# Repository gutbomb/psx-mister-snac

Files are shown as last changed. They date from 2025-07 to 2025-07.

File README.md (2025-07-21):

# psx-mister-snac

This is based on schematics published here: https://github.com/blue212/SNAC-PSX

the screw holes in the case model are designed to use m2.5 screws and m2.5x4 heat set inserts.

You'll need a controller input unit from a real playstation.  it is designed to use the original ribbon cable.

Enjoy!

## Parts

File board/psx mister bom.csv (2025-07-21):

Id | Designator | Footprint | Quantity | Designation | Supplier and ref
1 | J3 | CONN-TH_AV-5 | 1 | AV-5 | BOOMELE(Boom Precision Elec) AV-5
2 | J1 | FPC-SMD_10P-P1.00-L3.4-W13.0 | 1 | AFB10-S10LCA-00 | JUSHUO AFB10-S10LCA-00
3 | U1 | SOT-23-3 | 1 | XC6206PxxxMR | Torex Semicon XC6206P332MR-G
4 | R1,R7,R4,R3,R5,R6,R2 | R_0603_1608Metric | 7 | 1K | YAGEO RC0603FR-071KL
5 | C1,C2 | C_0805_2012Metric | 2 | 1uf | Samsung Electro-Mechanics CL21B105KBFNNNE
6 | J2 | U-B-M9DD-W-1 | 1 | U-B-M9DD-W-1 | Korean Hroparts Elec U-B-M9DD-W-1

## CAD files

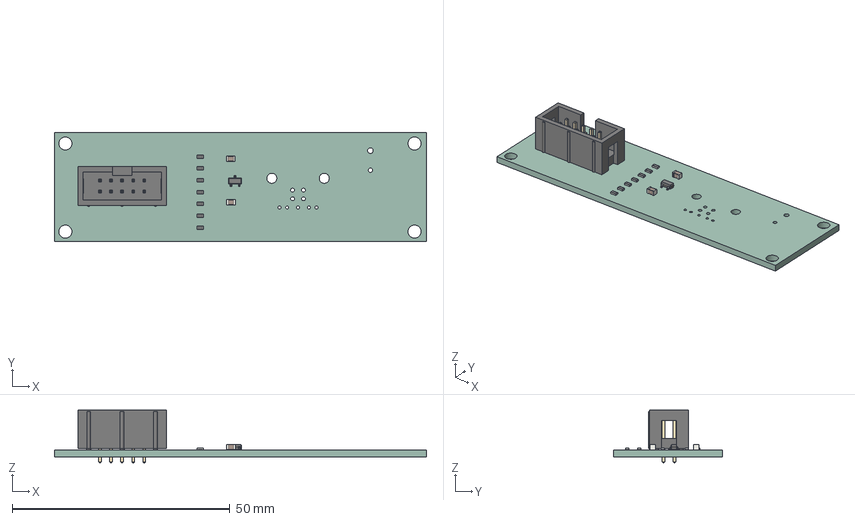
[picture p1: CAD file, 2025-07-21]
board/psx mister.step
85.5 x 25.0 x 12.1 mm
SOT-23-3
R_0603_1608Metric x 7
C_0805_2012Metric x 2
IDC_Header_2x05_P254mm_Vertical
psx mister_PCB

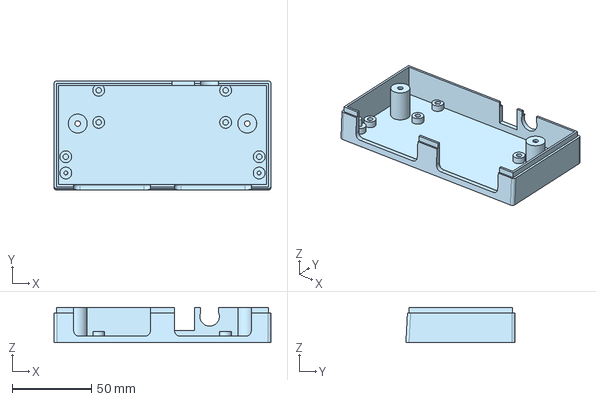
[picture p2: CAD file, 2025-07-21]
case/PSX Mister Case - Bottom.step
137.2 x 69.1 x 22.4 mm

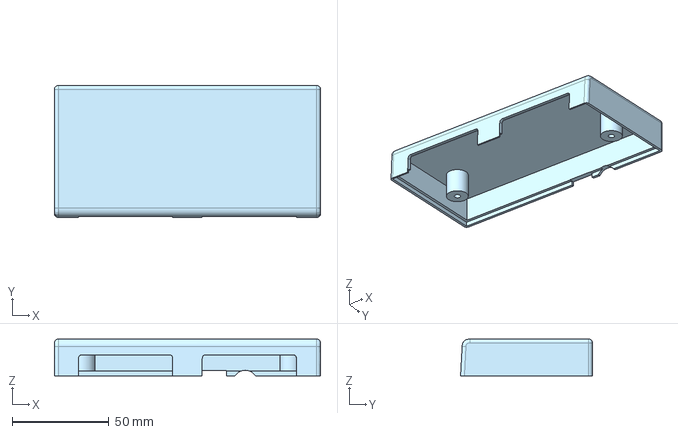
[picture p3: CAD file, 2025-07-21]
case/PSX Mister Case - Top.step
137.2 x 68.0 x 18.9 mm

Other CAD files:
case/PSX Mister Case - Bottom.stl
case/PSX Mister Case - Top.stl

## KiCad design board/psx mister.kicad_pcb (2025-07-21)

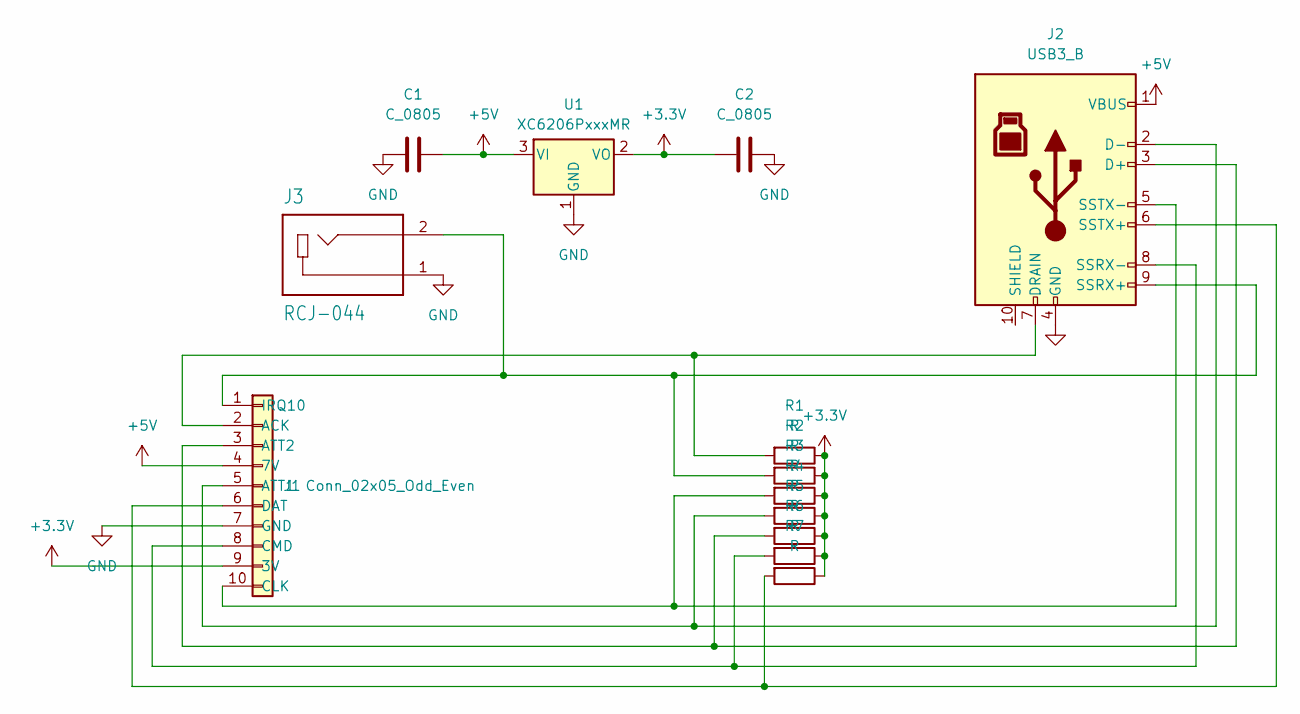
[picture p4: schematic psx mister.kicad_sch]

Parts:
C1, C2: C_0805; C_0805_2012Metric
J1: Conn_02x05_Odd_Even; FPC-SMD_10P-P1.00-L3.4-W13.0
J2: USB3_B; U-B-M9DD-W-1
J3: RCJ-044; CUI_RCJ-044
R1, R2, R3, R4, R5, R6, R7: R; R_0603_1608Metric
U1: XC6206PxxxMR; SOT-23-3

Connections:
+3.3V: C2.1, J1.9 (3V), R1.1, R2.1, R3.1, R4.1, R5.1, R6.1, R7.1, U1.2 (VO)
+5V: C1.2, J1.4 (7V), J2.1 (VBUS), U1.3 (VI)
GND: C1.1, C2.2, J1.7 (GND), J2.4 (GND), J3.1, U1.1 (GND)
unnamed: J1.2 (ACK), J2.7 (DRAIN), R1.2
unnamed: J1.5 (ATT1), J2.2 (D-), R4.2
unnamed: J1.3 (ATT2), J2.3 (D+), R5.2
unnamed: J1.10 (CLK), J2.5 (SSTX-), R3.2
unnamed: J1.8 (CMD), J2.8 (SSRX-), R6.2
unnamed: J1.6 (DAT), J2.6 (SSTX+), R7.2
unnamed: J1.1 (IRQ10), J2.9 (SSRX+), J3.2, R2.2

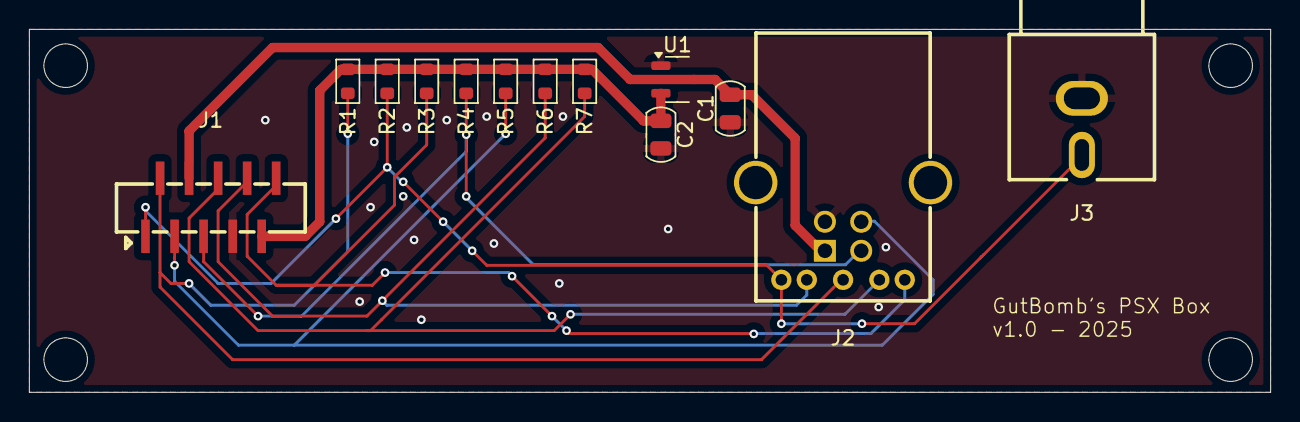
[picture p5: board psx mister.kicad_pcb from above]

Board: 2 copper layers, 85.5 x 25.0 mm, 13 parts (0 on the bottom side), 10 nets.

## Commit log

2025-07-21 public release
    [PSX Mister Case - Bottom.step, PSX Mister Case - Bottom.stl, PSX Mister Case - Top.step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]
2025-07-21 fixed error
    [psx mister.kicad_pcb, psx mister.kicad_sch]
2025-07-21 fixed error again
    [psx mister.kicad_pcb]
